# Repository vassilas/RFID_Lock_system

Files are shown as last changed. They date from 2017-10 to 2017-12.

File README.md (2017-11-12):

# RFID Lock System

The main Goal of this project it to develop a system whick cotrols a door-lock with a relay.
To unlock the door successfully you need to place three different RFID tags in
specific rfid reader's potitions . 

## Getting Started

The wirign is described in the source code (<project_folder>/src) 
Serial Monitor is used for testing the status of the system .

### Prerequisites

What things you need to install the software and how to install them

```
1) Arduino IDE
2) AddicoreRFID library
3) RFID livrary
```
## Schematic Image

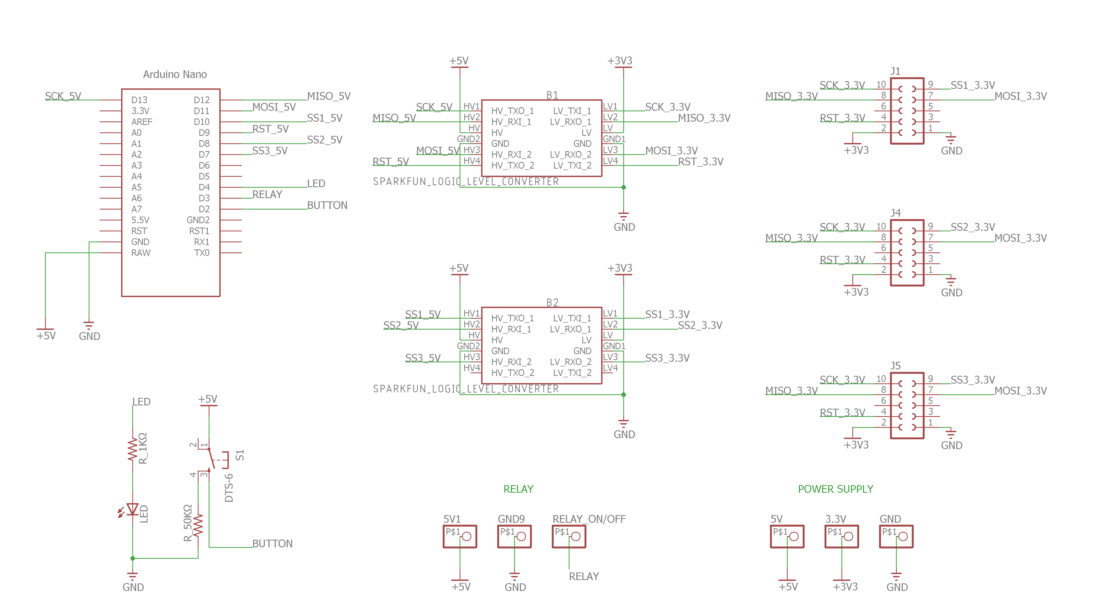
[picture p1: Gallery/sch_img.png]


## Layout Image

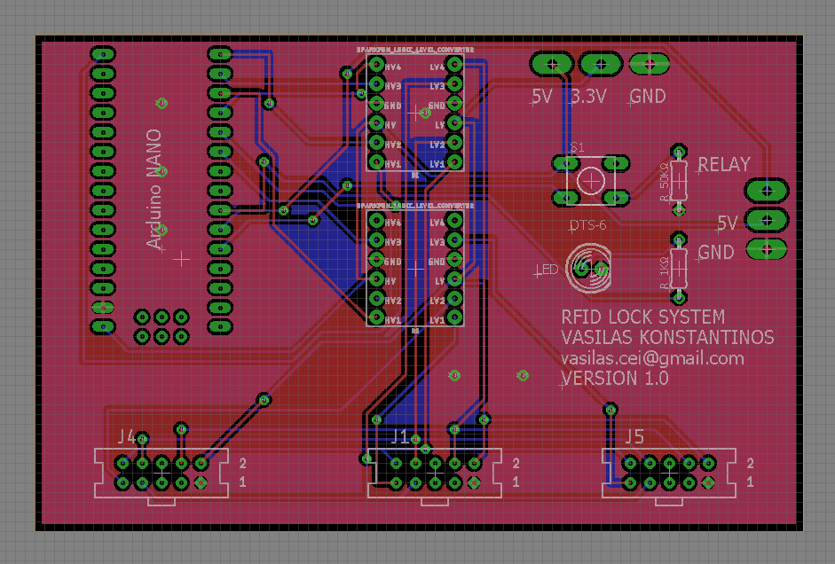
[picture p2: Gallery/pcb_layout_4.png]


## Some usefull links

* https://www.addicore.com/RFID-AddiKit-p/126.htm - RFID AddiKit with RC522

## Future plans

1. Extend the range of RFID reader 
2. Add tow more RFID readers 
3. power the relay only when specific RFID tags are present

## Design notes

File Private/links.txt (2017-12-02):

make a simple Arduino RFID reader using the RC522 Module
https://brainy-bits.com/blogs/tutorials/card-reader-with-an-arduino-rfid-using-the-rc522-module

Relay Module 
http://www.microbot.it/documents/mr009-001-2_datasheet.pdf

Issue sharing MISO with multiple RC522 RFID Readers
https://arduino.stackexchange.com/questions/18313/issue-sharing-miso-with-multiple-rc522-rfid-readers

Arduino RC522 RFID Door Unlock
http://www.instructables.com/id/Arduino-RC522-RFID-Door-Unlock/

Electronics Store
https://www.hellasdigital.gr

---------------------------------------
OTHER RFID READER MODULE
---------------------------------------
http://tronixstuff.com/2013/11/19/arduino-tutorials-chapter-15-rfid/

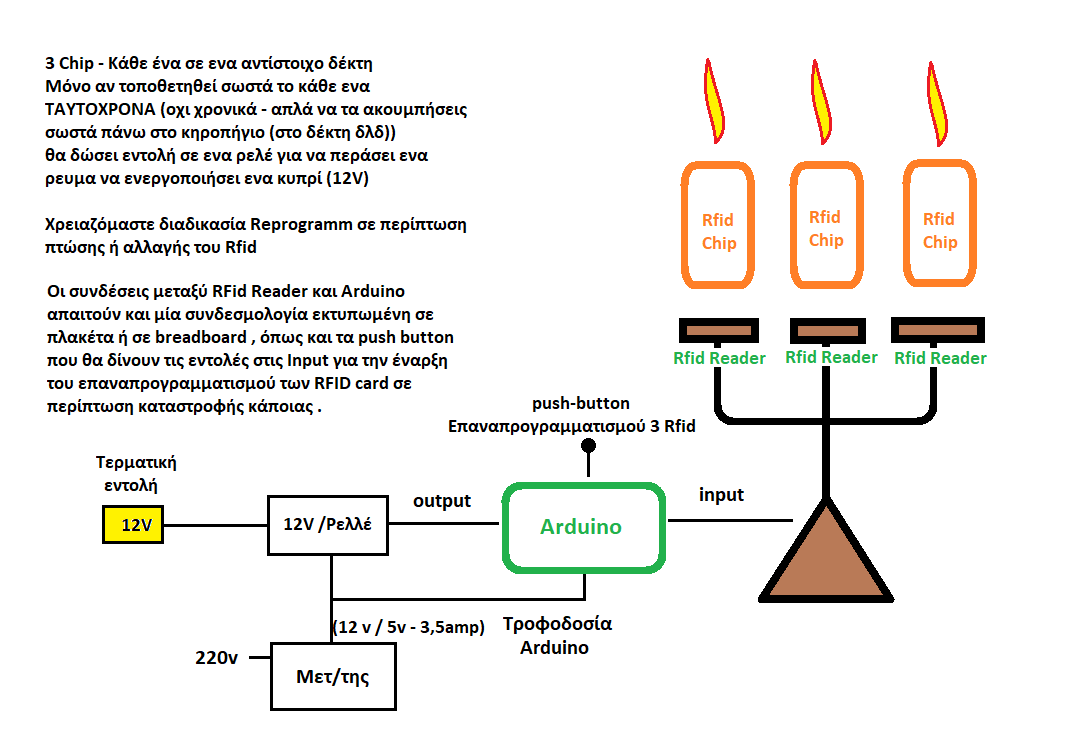
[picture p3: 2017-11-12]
Private/Architecture.bmp

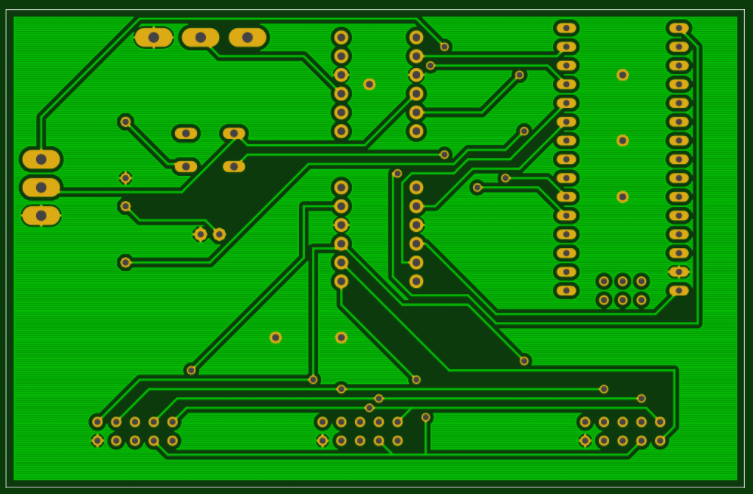
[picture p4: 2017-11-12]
Gallery/pcb_layout_3.png

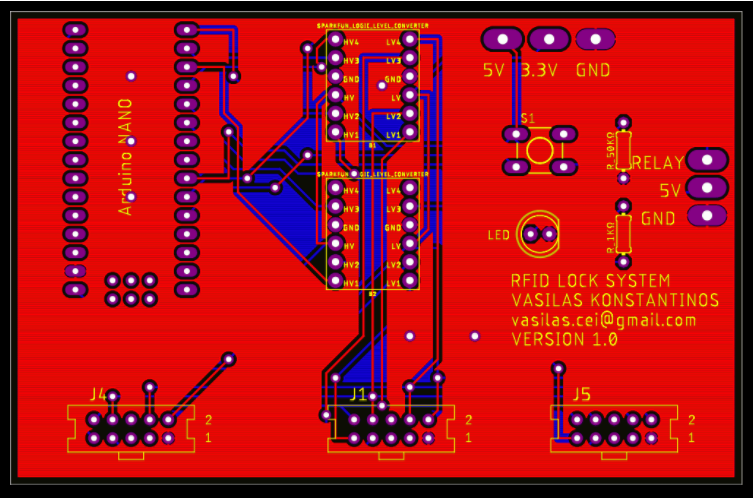
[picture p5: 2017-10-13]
Gallery/pcb_layout_1.png

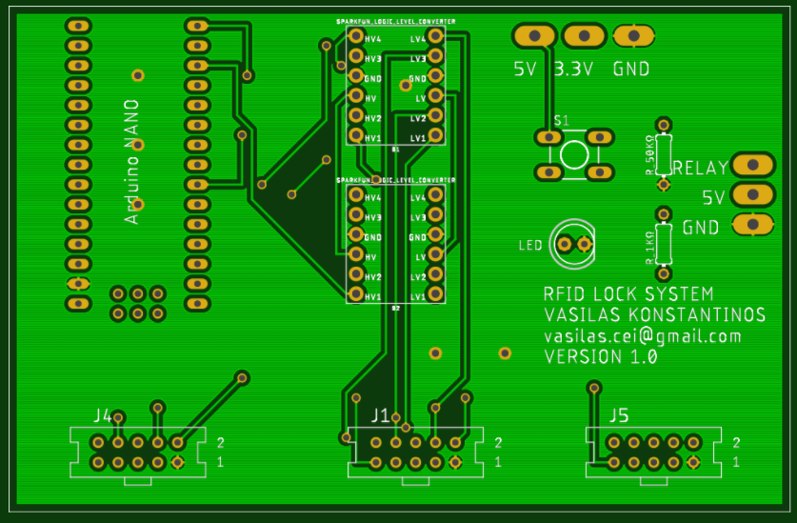
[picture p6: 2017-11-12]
Gallery/pcb_layout_2.png

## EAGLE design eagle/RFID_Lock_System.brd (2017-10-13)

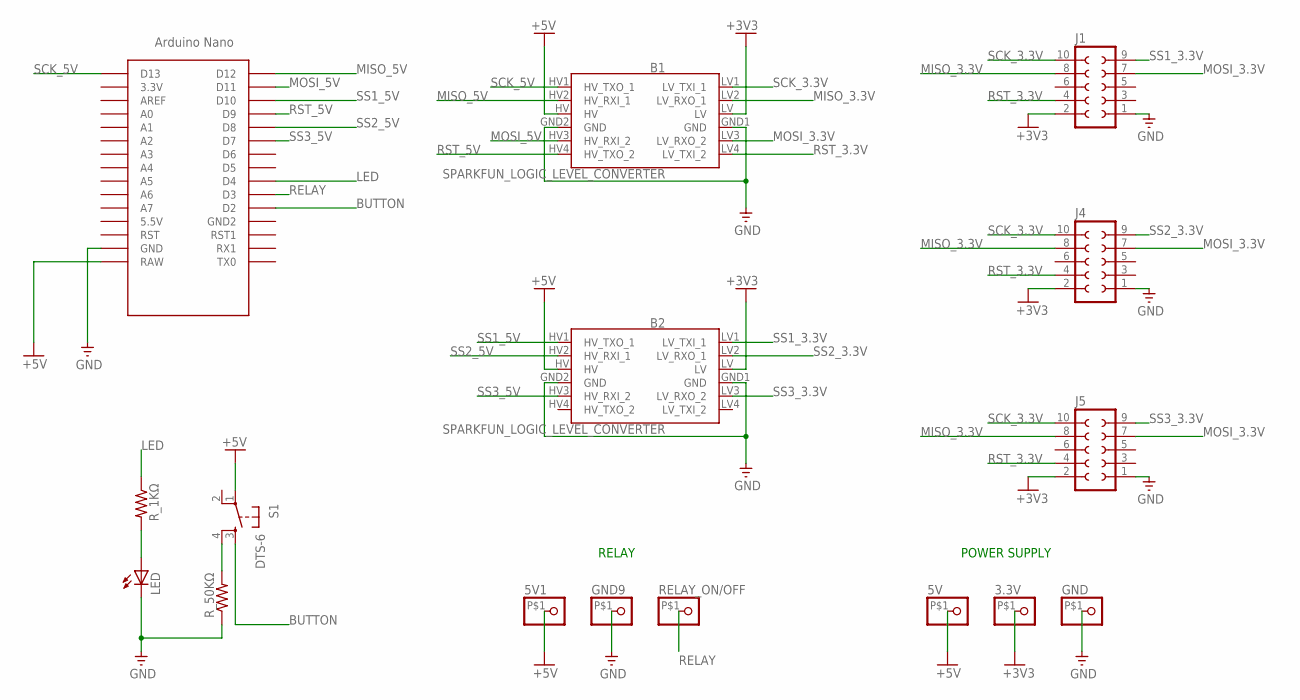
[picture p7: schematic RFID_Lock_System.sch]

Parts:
3.3V, 5V, 5V1: PINHD-1X1-BIGPOGO; 1X1-BIGPOGO
B1, B2: SPARKFUN_LOGIC_LEVEL_CONVERTER
GND, GND9: PINHD-1X1-BIGPOGO; 1X1-BIGPOGO
J1, J4, J5: SOCKET-10V; S10V
LED: LED5MM
RELAY_ON/OFF: PINHD-1X1-BIGPOGO; 1X1-BIGPOGO
R_1KΩ, R_50KΩ: R-US_0204/7; 0204/7
S1: DTS-6; MPN MC32829
U$1: NANO

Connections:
+3V3: 3.3V.P$1, B1.LV, B2.LV, J1.2, J4.2, J5.2
+5V: 5V.P$1, 5V1.P$1, B1.HV, B2.HV, S1.1, U$1.RAW
BUTTON: S1.3, U$1.D2
GND: B1.GND1 (GND), B1.GND2 (GND), B2.GND1 (GND), B2.GND2 (GND), GND.P$1, GND9.P$1, J1.1, J4.1, J5.1, LED.K (C), R_50KΩ.1, U$1.GND
LED: R_1KΩ.1, U$1.D4
MISO_3.3V: B1.LV2 (LV_RXO_1), J1.8, J4.8, J5.8
MISO_5V: B1.HV2 (HV_RXI_1), U$1.D12
MOSI_3.3V: B1.LV3 (LV_RXO_2), J1.7, J4.7, J5.7
MOSI_5V: B1.HV3 (HV_RXI_2), U$1.D11
unnamed: LED.A, R_1KΩ.2
unnamed: R_50KΩ.2, S1.4
RELAY: RELAY_ON/OFF.P$1, U$1.D3
RST_3.3V: B1.LV4 (LV_TXI_2), J1.4, J4.4, J5.4
RST_5V: B1.HV4 (HV_TXO_2), U$1.D9
SCK_3.3V: B1.LV1 (LV_TXI_1), J1.10, J4.10, J5.10
SCK_5V: B1.HV1 (HV_TXO_1), U$1.D13
SS1_3.3V: B2.LV1 (LV_TXI_1), J1.9
SS1_5V: B2.HV1 (HV_TXO_1), U$1.D10
SS2_3.3V: B2.LV2 (LV_RXO_1), J4.9
SS2_5V: B2.HV2 (HV_RXI_1), U$1.D8
SS3_3.3V: B2.LV3 (LV_RXO_2), J5.9
SS3_5V: B2.HV3 (HV_RXI_2), U$1.D7

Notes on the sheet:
POWER SUPPLY
RELAY

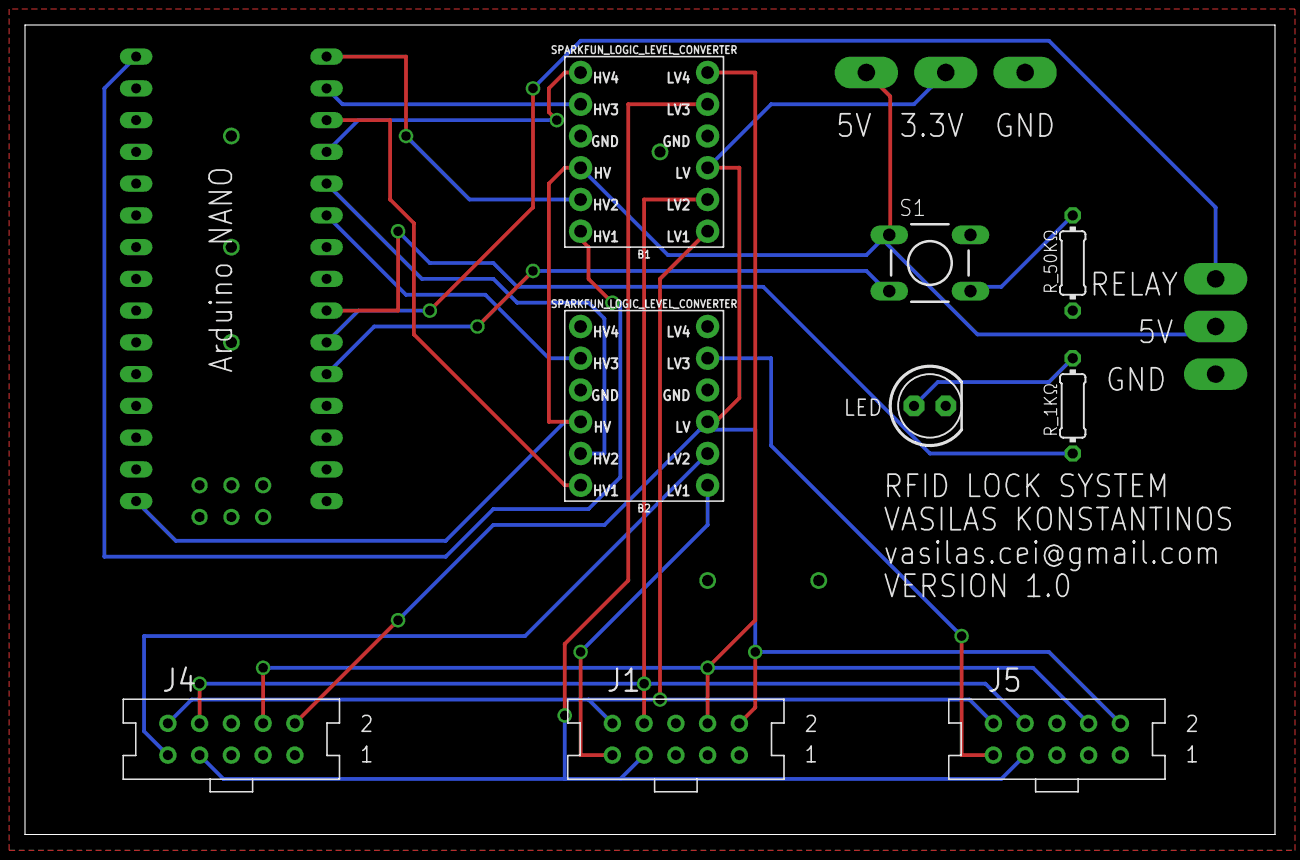
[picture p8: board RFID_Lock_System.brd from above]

Board: 2 copper layers, 100.0 x 64.8 mm, 16 parts (0 on the bottom side), 22 nets.

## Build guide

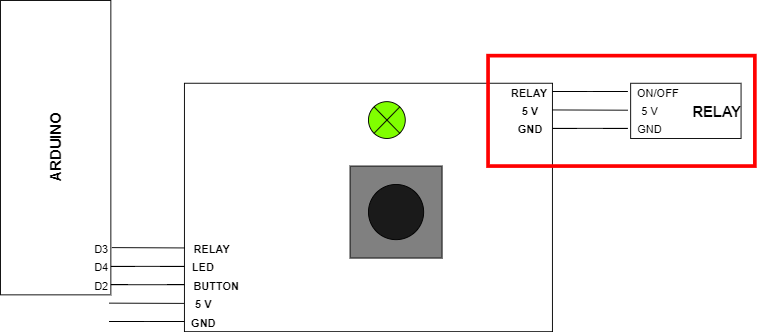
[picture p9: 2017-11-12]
Private/relay_assembly.png

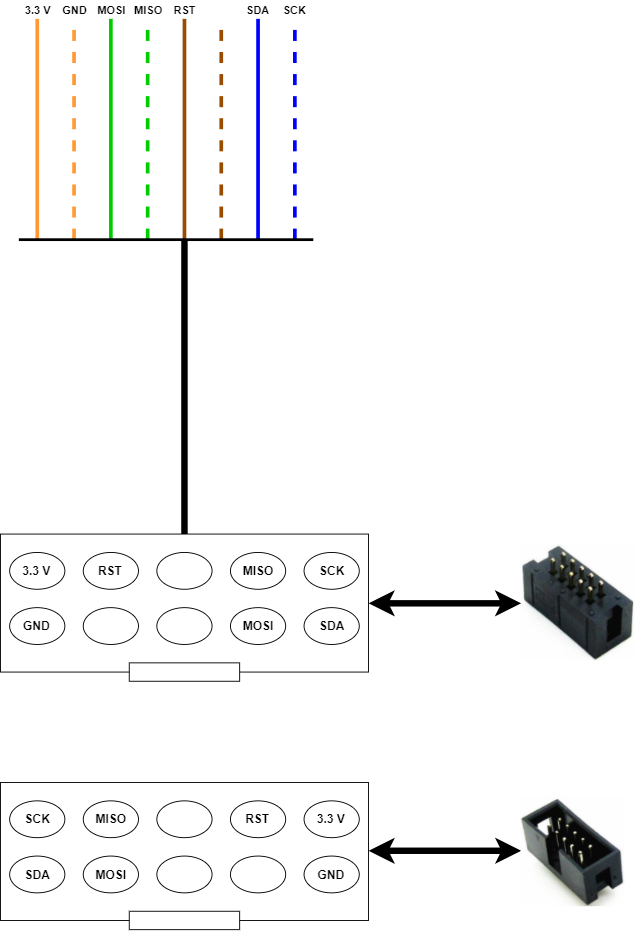
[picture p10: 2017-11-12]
Private/Network_assembly.png

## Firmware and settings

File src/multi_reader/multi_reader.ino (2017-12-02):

//-------------------------------------------------------------------------------------------------
/* Pin layout used:
 * ----------------------------------
 *             MFRC522      Arduino
 *             Reader/PCD   Uno/101
 * Signal      Pin          Pin
 * ----------------------------------
 * RST/Reset   RST          9
 * SPI MOSI    MOSI         11
 * SPI MISO    MISO         12 
 * SPI SCK     SCK          13
 * SS_1                     10
 * SS_2                     8
 * SS_3                     7
 * BUTTON                   2
 * RELAY                    3  
 * LED                      4
 */         
//-------------------------------------------------------------------------------------------------



#include <SPI.h>
#include <MFRC522.h>
#include <EEPROM.h>

// -- DEBUGGING MODE --
//
// Uncomment the following define to enter the debug mode
// Messeges will be printed to serial monitor 
//-------------------------------------------------------
#define DEBUG
//-------------------------------------------------------

#define TRUE 1
#define FALSE 0

//
//-------------------------------------------------------------------------------------------------
const uint8_t RST_PIN = 9;

const uint8_t SS_1_PIN = 10;
const uint8_t SS_2_PIN = 8;
const uint8_t SS_3_PIN = 7;

const uint8_t button = 2;
const uint8_t relay = 3;
const uint8_t led = 4;

//
//-------------------------------------------------------------------------------------------------
const uint8_t NR_OF_READERS = 3;
byte ssPins[] = {SS_1_PIN, SS_2_PIN, SS_3_PIN};

unsigned int relay_on_loops = 10 ;           // 0        : turn of ,
                                            // > 0      : turn on 

MFRC522 mfrc522[NR_OF_READERS];   



// SETUP
//-------------------------------------------------------------------------------------------------
void setup() 
{

    Serial.begin(9600);
    while (!Serial);
    
    SPI.begin();
    
    pinMode(button,INPUT);
    pinMode(relay,OUTPUT);
    pinMode(led,OUTPUT);
    
    digitalWrite(relay, LOW);
    digitalWrite(led, HIGH);

#ifdef DEBUG  
    print_serial_eeprom(0);
    print_serial_eeprom(4);
    print_serial_eeprom(8);
#endif
    
    for (uint8_t reader = 0; reader < NR_OF_READERS; reader++)
    {
        mfrc522[reader].PCD_SetAntennaGain((byte)0x7);
        mfrc522[reader].PCD_Init(ssPins[reader], RST_PIN);

    }
}



// LOOP
//-------------------------------------------------------------------------------------------------
void loop() 
{
    byte cards[NR_OF_READERS][4] ;
    int count = 0 ;
    int valid_read_count = 0 ;

    for(int i=0 ; i < NR_OF_READERS ; i++ )
        for(int j=0 ; j < 4 ; j++ )
            cards[i][j] = (byte)0;


    for (uint8_t reader = 0; reader < NR_OF_READERS; reader++) {
        
        bool tag_pressent = FALSE ;

        for( uint8_t i = 0 ; i <= 1 ; i++)
        {
            if (mfrc522[reader].PICC_IsNewCardPresent() && mfrc522[reader].PICC_ReadCardSerial())
            {
                
                tag_pressent = TRUE ;
                valid_read_count++;

                byte card_id[] =    {   mfrc522[reader].uid.uidByte[0] ,
                                        mfrc522[reader].uid.uidByte[1] ,
                                        mfrc522[reader].uid.uidByte[2] ,
                                        mfrc522[reader].uid.uidByte[3] ,
                                    };
                 
         
                print_serial_card_id( reader , card_id);
                delay(200);
                
                
                for(int i = 0 ; i < 4 ; i++ )
                    cards[reader][i] = card_id[i];
                
                
                if( digitalRead(button) == HIGH )
                {
                    Serial.print("\n> Register Card on Reeader : " + String(reader));
                    eeprom_write( (unsigned int)reader << 2 , card_id );
                }
            }
        }
        

        if(!tag_pressent)
        {
            if( digitalRead(button) == HIGH )
                Serial.print("\nERROR : At least one of the reader does not scan any RFID-tag");
        }

    }
    


    if( digitalRead(button) == HIGH )
        Serial.print("\nButton Pressed");
    
    for(int reader = 0 ; reader < NR_OF_READERS ; reader++)
        for(int field = 0 ; field < 4 ; field++ )
            if( cards[reader][field] == (byte)EEPROM.read(reader*4 + field) )
                count++ ;

    // LED CONTROL 
    // Indicates if all readers are recognize a tag
    //----------------------------------------------
    if(valid_read_count == NR_OF_READERS)
        digitalWrite(led, HIGH);
    else
        digitalWrite(led, LOW); 


    // RELAY CONTROL
    //----------------------------------------------
    if(count == NR_OF_READERS*4)
    {
        digitalWrite(relay, HIGH);
        

        // Add a dellay for relay to stay on
        //--------------------------------------------------------
        //if(relay_on_loops > 0 )
        //    for(unsigned int i = 0 ; i <= relay_on_loops ; i++)
        //    {
        //        delay(200);
        //        if(i == relay_on_loops ) digitalWrite(relay, LOW);    
         //   }
    }    
    else digitalWrite(relay, LOW);
  


     
}





//-------------------------------------------------------------------------------------------------
void print_serial_card_id( uint8_t reader , byte *id )
{
    Serial.print("\nReader " + String(reader) + " :");
    Serial.print("\n"  + String(id[0]) + " , " + String(id[1]) );
    Serial.print(" , " + String(id[2]) + " , " + String(id[3]) );
    Serial.print("\n");
    
}




//-------------------------------------------------------------------------------------------------





// EEPROM FUNCTIONS
//-------------------------------------------------------------------------------------------------
void print_serial_eeprom( int start_address )
{
    Serial.print("\nEEPROM DATA , Address " + String(start_address) + " :\n");
    Serial.print(   String(EEPROM.read(start_address))   + " , " + 
                    String(EEPROM.read(start_address+1)) + " , " + 
                    String(EEPROM.read(start_address+2)) + " , " + 
                    String(EEPROM.read(start_address+3))
                );
    Serial.print("\n");
}



void eeprom_write(const unsigned int start_address, byte *id)
{
    for(int i = 0 ; i < 4 ; i++)
        EEPROM.write(start_address+i, id[i]);
}



void wipe_eeprom()
{
    int i = 0 ;

    for(i=0 ; i<EEPROM.length() ; i++ )
        EEPROM.write(i,0);

}





/*
    Notes:
        - Command to aneble write to USB port where arduino is connected:
            > sudo chown vasilas /dev/ttyUSB0



*/

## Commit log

2017-09-14 [SW] Recognize Presence of a RFID Tag - Print status to LCD
2017-09-15 [SW] Include Relay control . The relay status change when a RFID tag is recognized
2017-09-15 Initialize Schematic with Eagle
    [Schematic.sch]
2017-09-15 [SW] Save last RFID Tag's id readed into EEPROM of the AVR and print it on restart/start-up
2017-09-15 [SW] Register a button to togle the state of the relay
2017-09-18 [SW] Add support for relay control , and button
2017-09-20 [SW] Adding three modules RC522 on a single Arduino UNO , Using MFRC522.h Library
2017-09-21 [SW] Add a button , its' function : When it's pressed rfid tags are saved in EEPROM
2017-09-27 [SW] Proper read from the tags . In each cycle each reader get tow requests , This is sovling the synchronization issue due to rfid-read after the recognition of a tag follows a non-pressented tag cy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
    [multi_reader.ino]
2017-09-27 [SW] Add debug mode with serial monitoring the states of the system, Re-order led control with relay control
2017-10-13 Add eagle schematic and PCB files
    [RFID_Lock_System.brd, RFID_Lock_System.sch, Schematic.sch]
2017-11-12 Update gallery with pcb layouts , update private section with some architecture schematics
2017-12-02 Update SW , some modifications for the relay control , and Links text file

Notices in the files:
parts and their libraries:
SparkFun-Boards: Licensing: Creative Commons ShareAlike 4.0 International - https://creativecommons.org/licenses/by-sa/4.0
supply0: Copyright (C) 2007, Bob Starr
